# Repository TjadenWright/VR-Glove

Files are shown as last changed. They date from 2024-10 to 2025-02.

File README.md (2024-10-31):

# VR-Glove
Base Glove Front On

# 3D Printing [here](https://github.com/TjadenWright/VR-Glove/tree/main/Hardware/3D%20Print/README.md)

# Electrical [here](https://github.com/TjadenWright/VR-Glove/tree/main/Hardware/Electrical/README.md)

# Software [here](https://github.com/TjadenWright/VR-Glove/tree/main/Software/README.md)
* UWB findings [here](https://github.com/TjadenWright/VR-Glove/blob/main/Software/UWB%20VR%20Glove%20Communication/README.md)

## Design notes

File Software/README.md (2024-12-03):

# Program the VR Glove
* Open [this file](https://github.com/TjadenWright/VR-Glove/tree/main/Software/VR%20Glove%20-%20LucidVR/lucidgloves-firmware/lucidgloves-firmware.ino) in Arduino and program that to the glove arduino.
Full Glove

# Program the Receiver
## BLE
* Open [this file](https://github.com/TjadenWright/VR-Glove/blob/main/Software/Receiver%20-%20UART%20bridge/UART_bridge/UART_bridge.ino) in Arduino and program that to the receiver arduino.
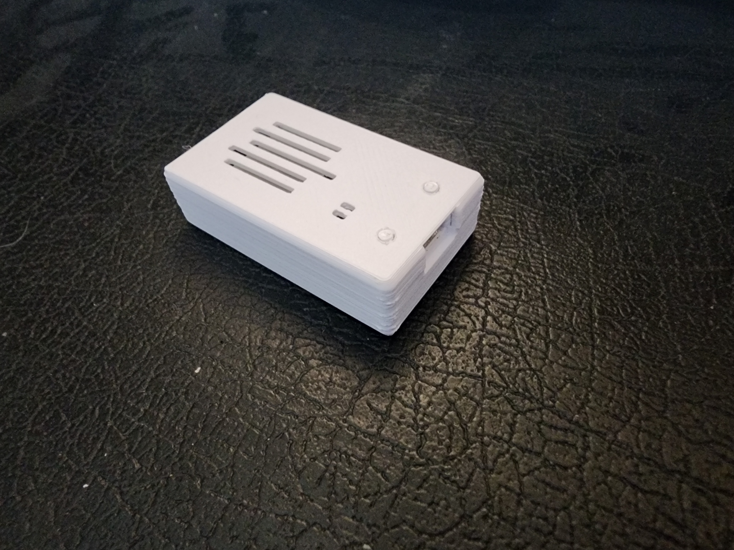
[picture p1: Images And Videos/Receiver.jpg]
Reciever


## UWB
* Open [this file](https://github.com/TjadenWright/VR-Glove/blob/main/Software/UWB%20VR%20Glove%20Communication/UWB%20Test%20Commands/BasicReceiver/BasicReceiver.ino) in Arduino and program that to the receiver arduino.

# References:
* https://github.com/DieKatzchen/lucidgloves/tree/proto5
* https://github.com/DieKatzchen/Nordic-UART-Service-Bridge

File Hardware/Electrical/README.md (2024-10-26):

# Wiring Diagram
## Glove + Joystick
* I mainly used [this](https://github.com/LucidVR/lucidgloves/wiki/Prototype-5-Wiring-Guide) wiring diagram for the glove and joystick.
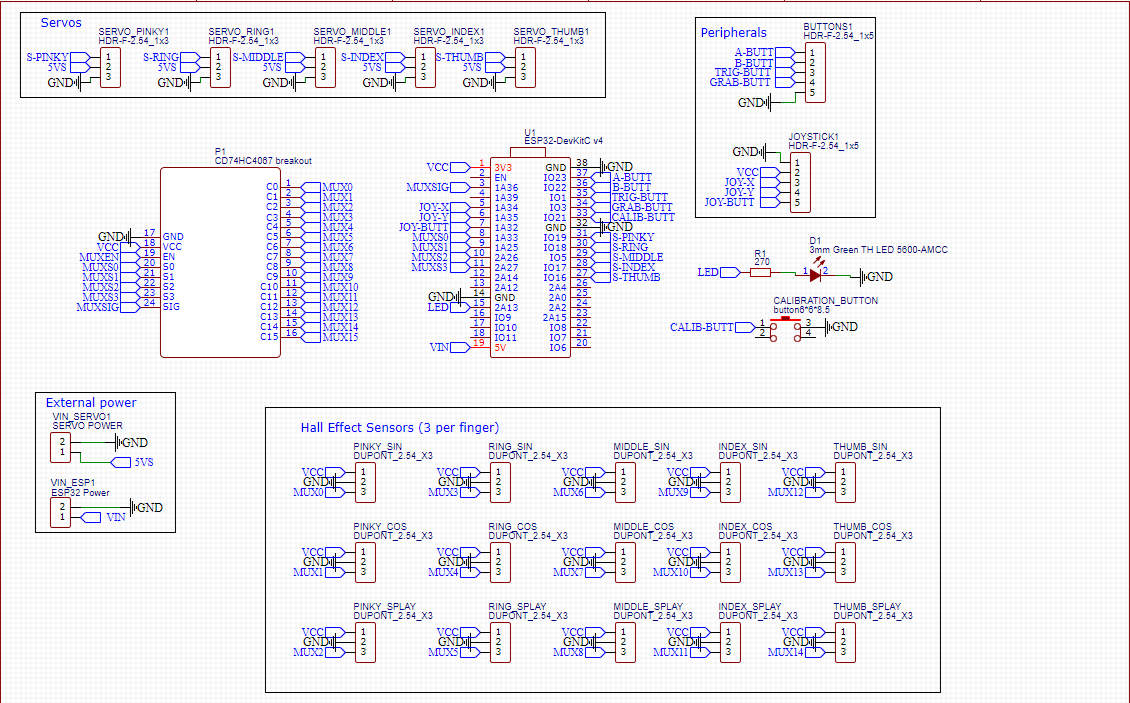
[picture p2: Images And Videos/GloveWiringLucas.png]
Glove Wiring


## Battery Pack
* For the battery circuit I used [this](https://docs.slimevr.dev/diy/tracker-schematics.html). If you want to charge while the glove is on you'll need to add two 1N5817 diodes on the output of the TP4056.
* For my specific ESP32 I needed to use a [boost converter](https://www.amazon.com/gp/product/B07L76KLRY/ref=ox_sc_act_title_3?smid=A1IU4FC9F8Y7P1&psc=1) to boost the batteries 3.7v to 5v. Do this on the wires going to the ESP32 (or the output of the TP4056).
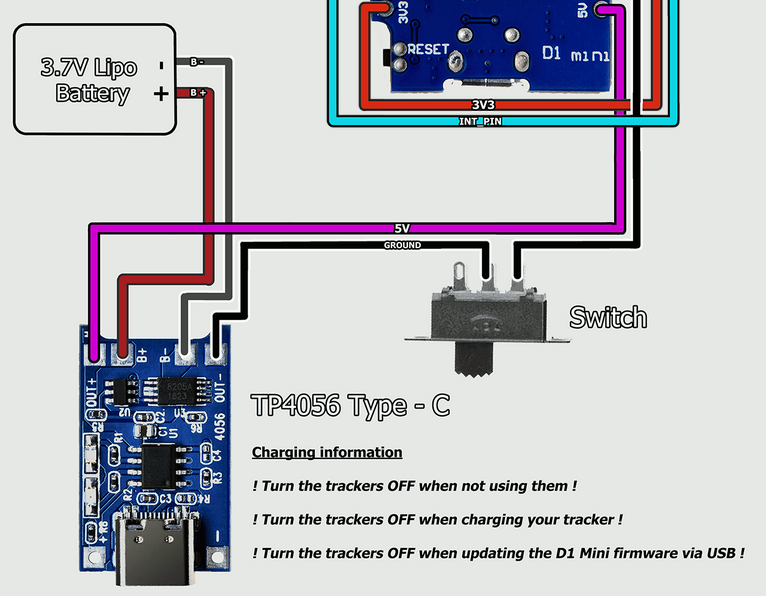
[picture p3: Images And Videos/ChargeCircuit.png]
Charge Circuit


# Parts List
## Base Glove
* 2x ESP32. I used [this](https://www.makerfabs.com/esp32-uwb-high-power-120m.html), I don't recoment that one. I just had that from another project. I recommend [this one](https://www.amazon.com/ESP-WROOM-32-Development-Microcontroller-Integrated-Compatible/dp/B0BK13HWBJ?th=1).
* 10x [Hall Effect Sensors](https://www.amazon.com/gp/aw/d/B09MSDC3GR?psc=1&ref=ppx_pop_mob_b_asin_title).
* 10x [Magnets](https://www.amazon.com/gp/aw/d/B08NZTN426?psc=1&ref=ppx_pop_mob_b_asin_title).
* 1x [Multiplexer](https://www.amazon.com/gp/aw/d/B07K7JF3HX?psc=1&ref=ppx_pop_mob_b_asin_title).
* [Wires](https://www.amazon.com/Elegoo-EL-CP-004-Multicolored-Breadboard-arduino/dp/B01EV70C78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).
* [M2 Screws](https://www.amazon.com/your-orders/pop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).
* (Optional): [Cable Sleeves](https://www.amazon.com/HERCULES-Paracord-Parachute-Black-Survival/dp/B0BD2J2DQV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).

## Joystick Upgrade
* 1x [Hall Joystick](https://www.aliexpress.us/item/3256806013522128.html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).
* 2x [Buttons](https://www.amazon.com/DAOKI-100Pcs-6x6x5mm-Momentary-Tactile/dp/B07X8T9D2Q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).
* 1x [Joystick Top](https://www.amazon.com/Joystick-Thumbsticks-Replacement-Controller-Accessories/dp/B0C3GHDLDW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).
* 4x [JST-XH Connectors](). One 3 pin (male, female) and one 4 pin (male, female) sets.
* [M2 Screws](https://www.amazon.com/your-orders/pop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).
* [Wires](https://www.amazon.com/Elegoo-EL-CP-004-Multicolored-Breadboard-arduino/dp/B01EV70C78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).
* (Optional): [Cable Sleeves](https://www.amazon.com/HERCULES-Paracord-Parachute-Black-Survival/dp/B0BD2J2DQV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).

## Battery Upgrade
* 1x [Battery](https://www.amazon.com/gp/product/B078TRCNRY/ref=ox_sc_act_title_2?smid=AQ7920MIUJ04Q&psc=1).
* 1x [Charge Board](https://www.amazon.com/HiLetgo-Lithium-Battery-Charging-Protect/dp/B00LTQU2RK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).
* 2x [JST-XH Connectors](). One 4 pin (male, female) set.
* 2x [Buttons](https://www.amazon.com/Gebildet-250VAC-Prewired-Momentary-Railway/dp/B083JWJPW5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). 
* [M2 Screws](https://www.amazon.com/your-orders/pop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).
* [Wires](https://www.amazon.com/Elegoo-EL-CP-004-Multicolored-Breadboard-arduino/dp/B01EV70C78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).
* (Optional): [Boost Converter](https://www.amazon.com/gp/product/B07L76KLRY/ref=ox_sc_act_title_3?smid=A1IU4FC9F8Y7P1&psc=1)
* (Optional): [Cable Sleeves](https://www.amazon.com/HERCULES-Paracord-Parachute-Black-Survival/dp/B0BD2J2DQV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).

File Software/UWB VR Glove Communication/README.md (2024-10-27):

# BLE 4.2 vs UWB
## BLE 4.2
* Pretty slow, at least compared to UWB. The data rate for serial is about 110 lines per second. BLE brings this data rate down to 34 lines per second or a 69.1% reduction.
BLE 4.2

## UWB
* Very fast, basically as fast as serial. The data rate for serial os about 110 lines per second. UWB brings this down to 104 lines per second or only a 5.5% reduction. 
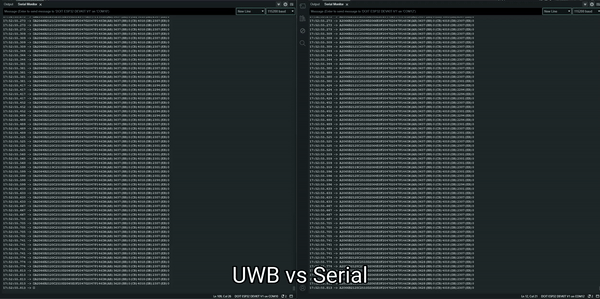
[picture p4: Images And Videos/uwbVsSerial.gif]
UWB


## UWB Board
* The board I used was the [ESP32 UWB Pro](https://www.makerfabs.com/esp32-uwb-high-power-120m.html). This also has the added benifit of having a range of ~200m, which is pretty crazy.
* If you have this board all you need to do is install [this libaray](https://github.com/TjadenWright/VR-Glove/tree/main/Software/UWB%20VR%20Glove%20Communication/README.md) and set your device to an DOIT ESP32 DEV Board.

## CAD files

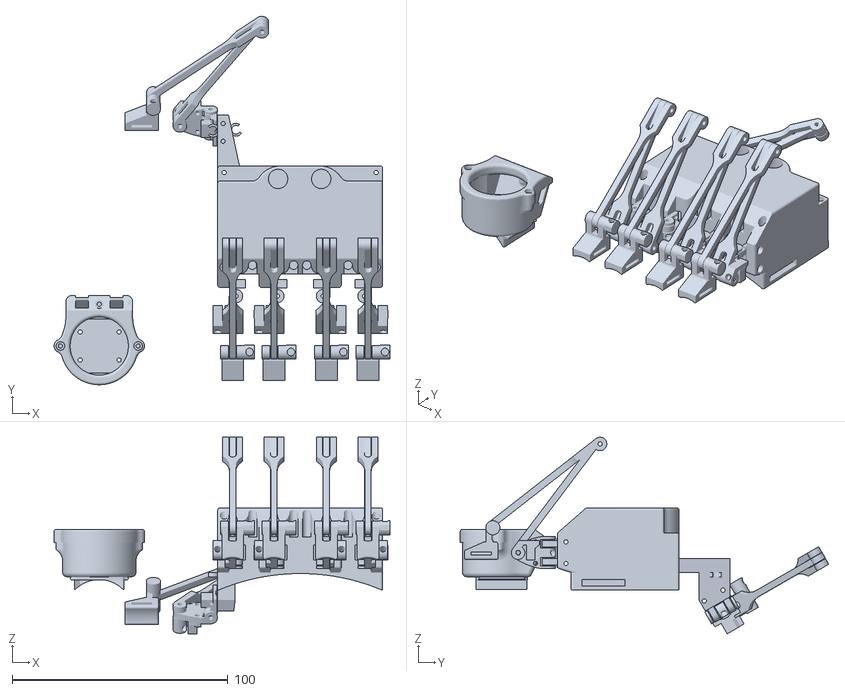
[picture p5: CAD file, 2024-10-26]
Hardware/3D Print/STLs/Full Glove/fullGlove v1.stl
155.9 x 171.0 x 91.2

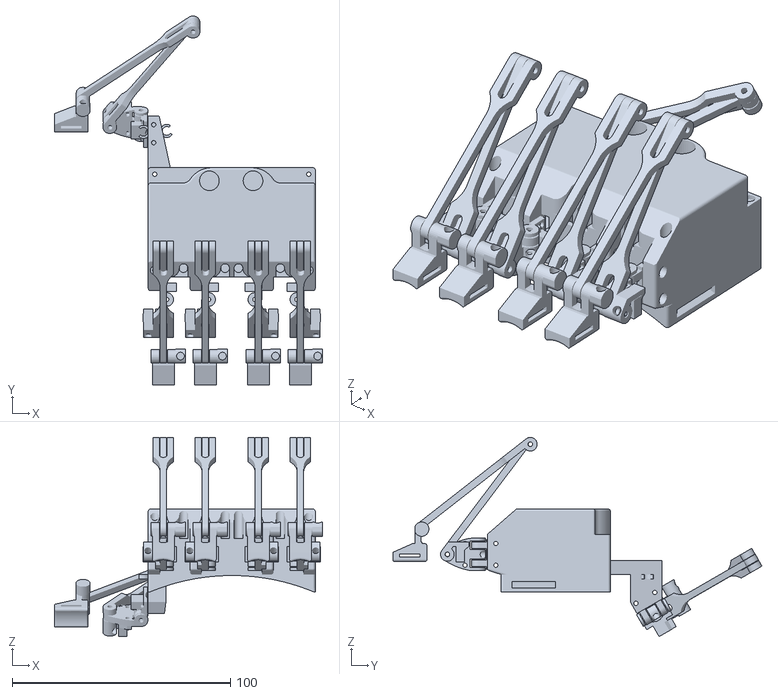
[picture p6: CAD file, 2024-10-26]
Hardware/3D Print/STLs/Base Glove + Battery Pack/baseGloveAndBatteryPack v1.stl
122.9 x 169.0 x 91.2

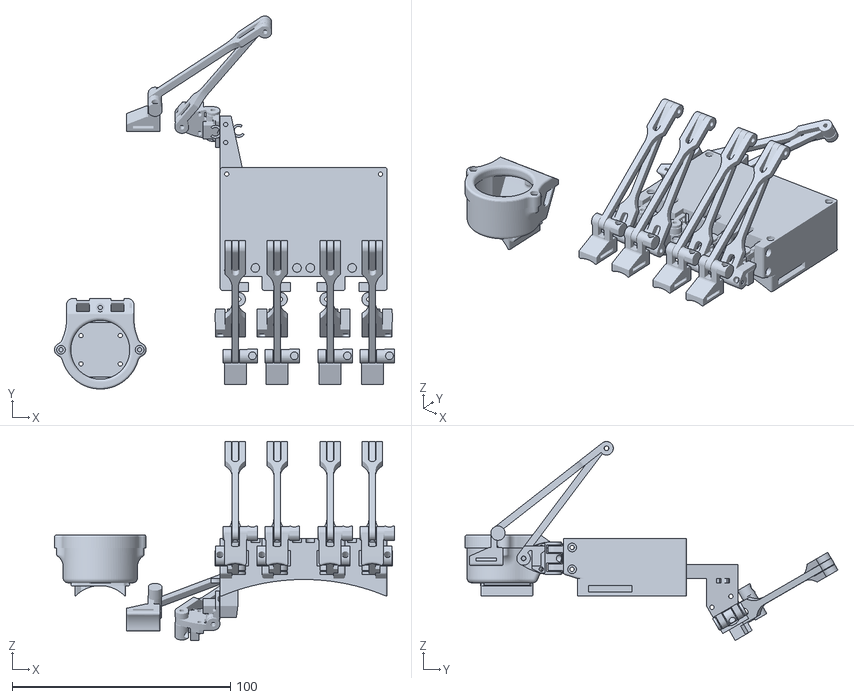
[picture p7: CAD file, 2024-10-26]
Hardware/3D Print/STLs/Base Glove + Joystick/baseGloveAndJoystick v1.stl
155.9 x 171.0 x 91.2

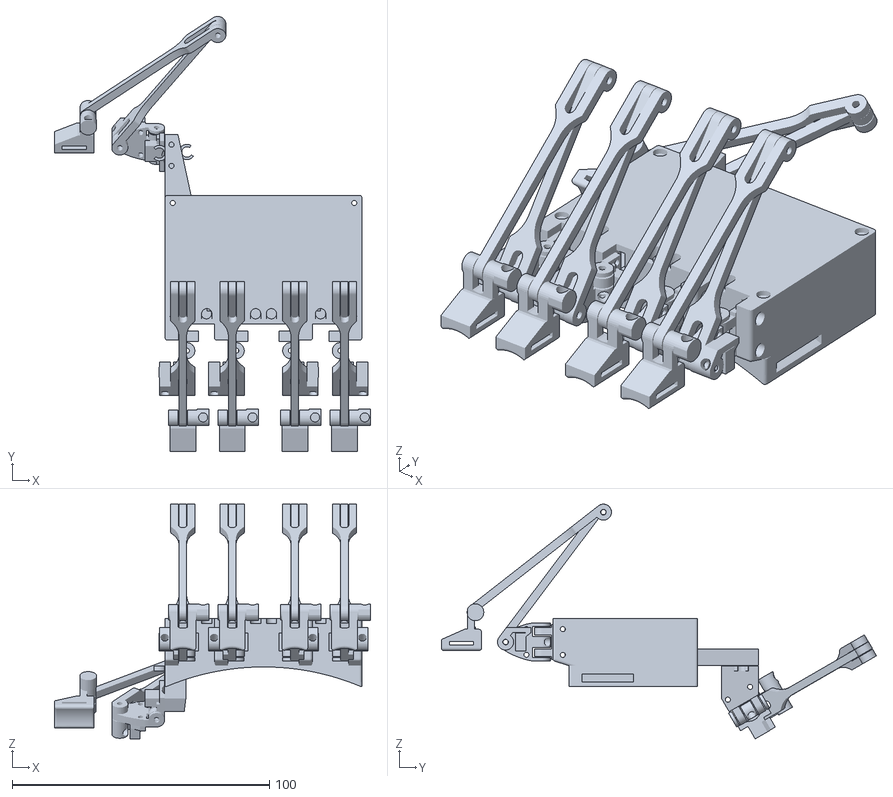
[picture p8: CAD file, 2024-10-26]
Hardware/3D Print/STLs/Base Glove/baseGlove v1.stl
122.9 x 169.0 x 91.2

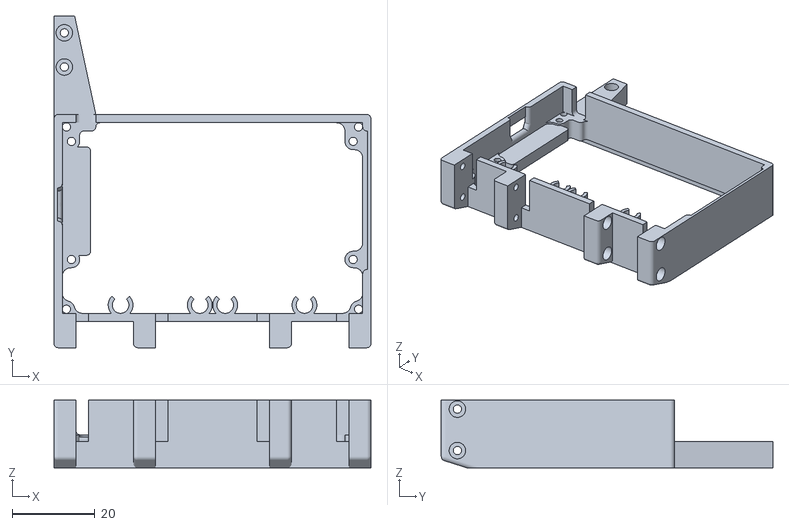
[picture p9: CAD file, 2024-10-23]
Hardware/3D Print/STLs/caseVrGlove/caseVrGlove v29.stl
76.5 x 80.0 x 16.4

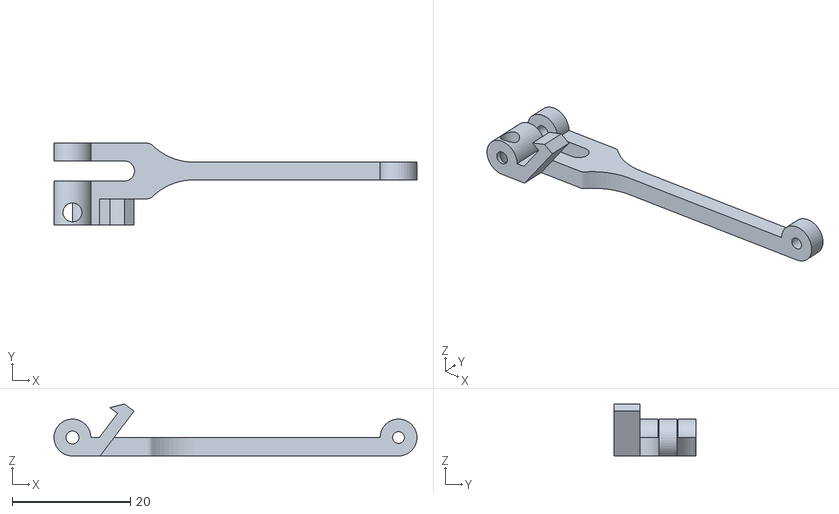
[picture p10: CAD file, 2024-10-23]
Hardware/3D Print/STLs/Parts/Base Parts/Bar Magnet/barMagnet v13small.stl
61.5 x 13.8 x 8.79

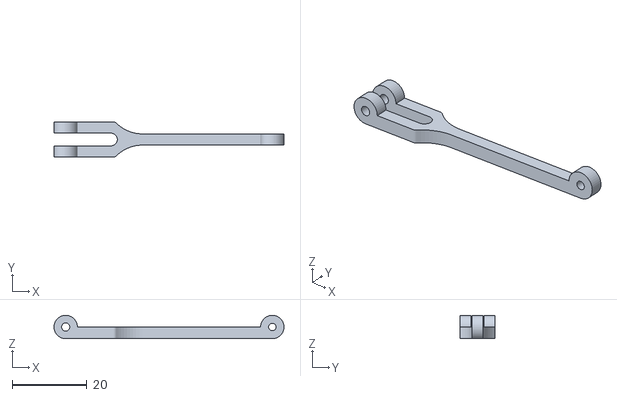
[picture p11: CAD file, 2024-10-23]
Hardware/3D Print/STLs/Parts/Base Parts/Bar/bar v8small.stl
61.5 x 9.40 x 6.25

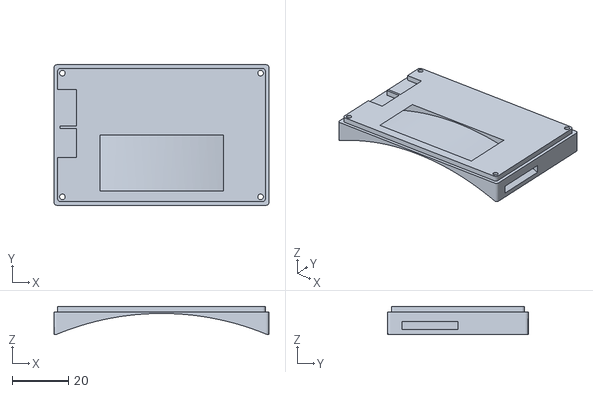
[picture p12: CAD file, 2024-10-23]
Hardware/3D Print/STLs/Parts/Base Parts/Bottom Lid Vr-Glove/bottomLidVrGlove v10.stl
76.5 x 50.0 x 10.0

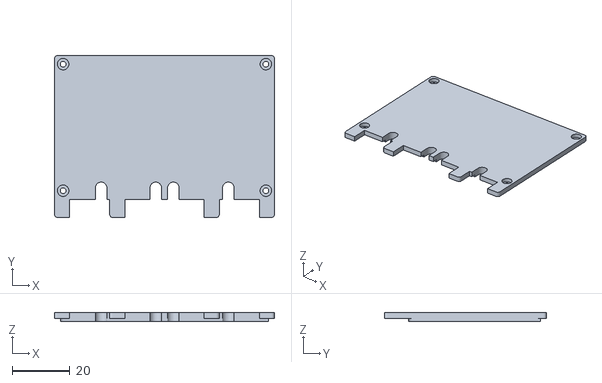
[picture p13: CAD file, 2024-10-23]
Hardware/3D Print/STLs/Parts/Base Parts/Case Lid Top/caseLidTop v7.stl
76.5 x 56.3 x 3.00

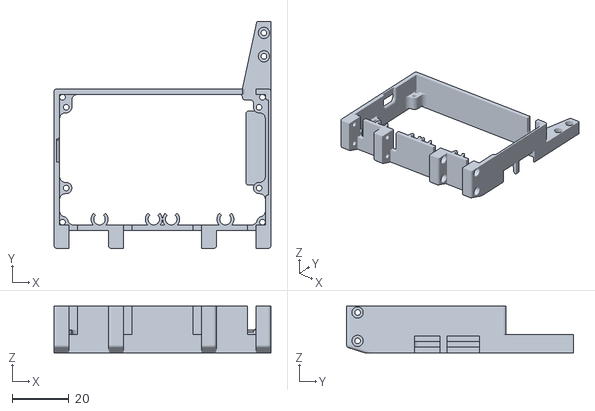
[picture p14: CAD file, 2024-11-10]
Hardware/3D Print/STLs/Parts/Base Parts/Case Vr-Glove/caseVrGloveRight v2.stl
76.5 x 80.0 x 16.4

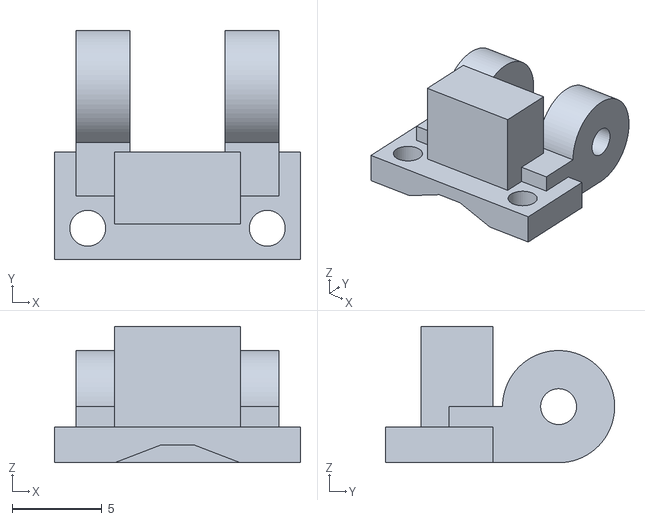
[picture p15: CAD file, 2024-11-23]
Hardware/3D Print/STLs/Parts/Base Parts/Hall Effect Holder Joint/hallEffectHolderJoint v8.stl
13.7 x 12.8 x 7.60

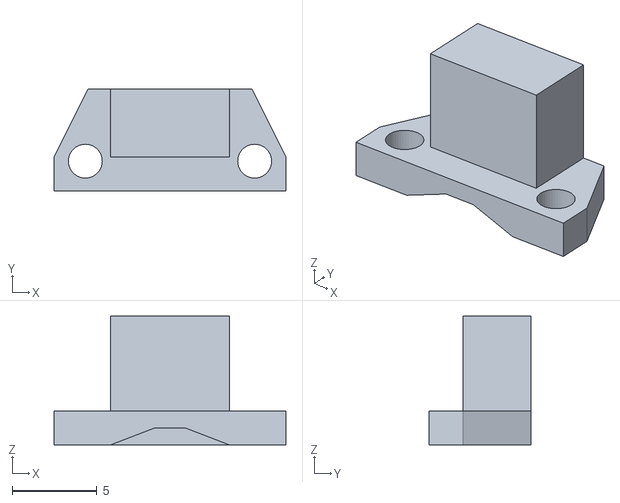
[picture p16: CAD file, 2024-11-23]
Hardware/3D Print/STLs/Parts/Base Parts/Hall Effect Holder/hallEffectHolder v9.stl
13.7 x 6.00 x 7.60

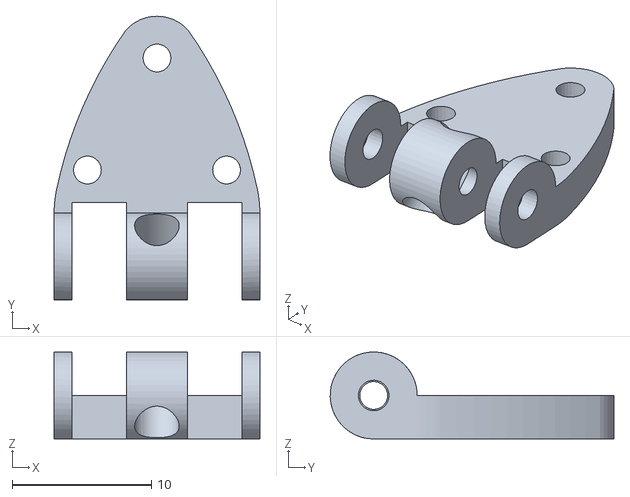
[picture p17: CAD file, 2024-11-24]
Hardware/3D Print/STLs/Parts/Base Parts/Splay Flex Joint/splayFlexJoint v21.stl
14.8 x 20.4 x 6.25

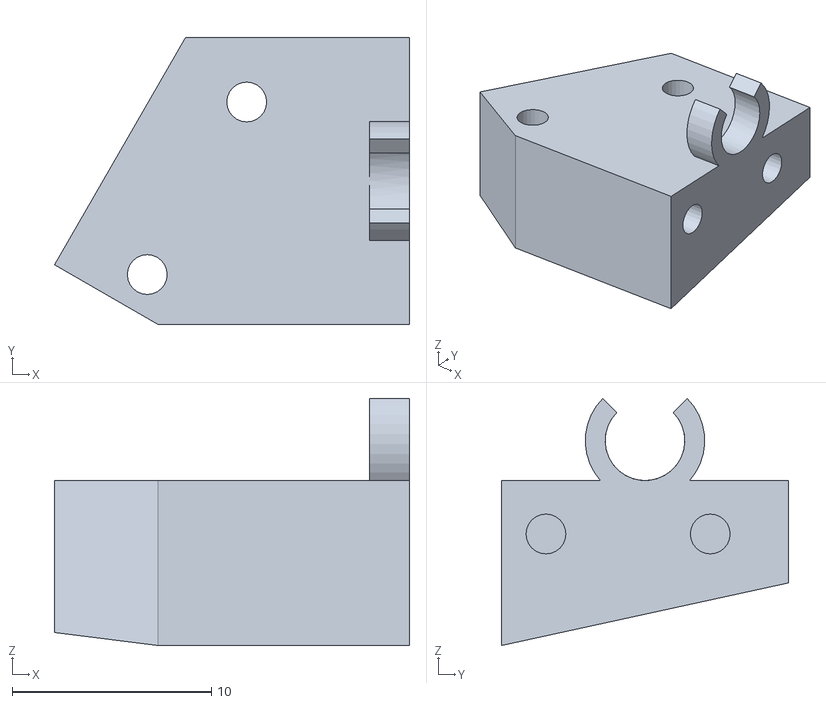
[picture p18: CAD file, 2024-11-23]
Hardware/3D Print/STLs/Parts/Base Parts/Thumb Extension/ThumbExtension v4.stl
17.8 x 14.4 x 12.4

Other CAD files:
Hardware/3D Print/STLs/Parts/Battery Pack/Battery Upgrade Lid/batteryUpgradeLid v6.stl
Hardware/3D Print/STLs/Parts/Battery Pack/Case Lid Top For Battery/caseLidTopForBattery v3.stl
Hardware/3D Print/STLs/Parts/Joystick And Buttons/Joystick Body/joystickBody v8.stl
Hardware/3D Print/STLs/Parts/Joystick And Buttons/Joystick Finger Mount/joystickFingerMount v6.stl
Hardware/3D Print/STLs/Parts/Base Parts/Bar Magnet/Old/barMagnet v10.stl
Hardware/3D Print/STLs/Parts/Base Parts/Bar Magnet/Old/barMagnet v11.stl
Hardware/3D Print/STLs/Parts/Base Parts/Bar Magnet/Old/barMagnet v4.stl
Hardware/3D Print/STLs/Parts/Base Parts/Bar Magnet/Old/barMagnet v5.stl
Hardware/3D Print/STLs/Parts/Base Parts/Bar Magnet/Old/barMagnet v6.stl
Hardware/3D Print/STLs/Parts/Base Parts/Bar Magnet/Old/barMagnet v7.stl
Hardware/3D Print/STLs/Parts/Base Parts/Bar Magnet/Old/barMagnet v9.stl
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

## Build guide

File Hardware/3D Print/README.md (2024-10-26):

# Full Glove With Battery Pack And Joystick Attachments
* The STL can be viewed [here](https://github.com/TjadenWright/VR-Glove/blob/main/Hardware/3D%20Print/STLs/Full%20Glove/fullGlove%20v1.stl).
* The 3D printing parts list can be viewed [here](https://github.com/TjadenWright/VR-Glove/blob/main/Hardware/3D%20Print/STLs/Full%20Glove/README.md).
Full Glove

# Base Glove
* The STL can be viewed [here](https://github.com/TjadenWright/VR-Glove/blob/main/Hardware/3D%20Print/STLs/Base%20Glove/baseGlove%20v1.stl).
* The 3D printing parts list can be viewed [here](https://github.com/TjadenWright/VR-Glove/blob/main/Hardware/3D%20Print/STLs/Base%20Glove/README.md).
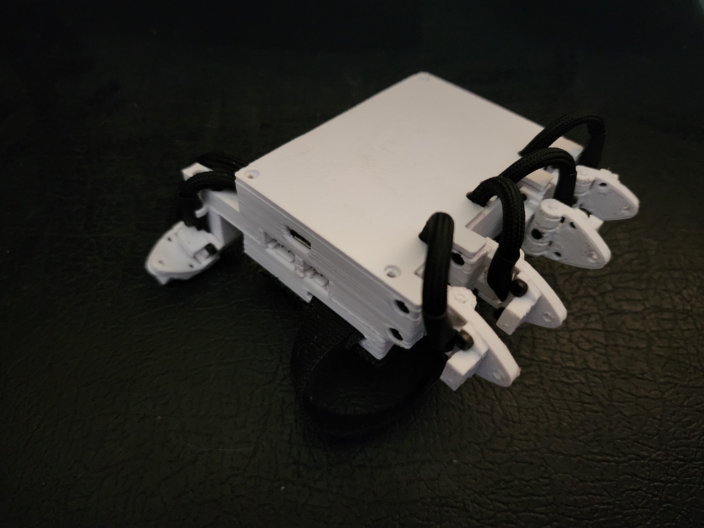
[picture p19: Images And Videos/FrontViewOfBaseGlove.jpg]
Base Glove


# Base Glove With Battery Pack
* The STL can be viewed [here](https://github.com/TjadenWright/VR-Glove/blob/main/Hardware/3D%20Print/STLs/Base%20Glove%20+%20Battery%20Pack/baseGloveAndBatteryPack%20v1.stl).
* The 3D printing parts list can be viewed [here](https://github.com/TjadenWright/VR-Glove/blob/main/Hardware/3D%20Print/STLs/Base%20Glove%20+%20Battery%20Pack/README.md).
Base Glove With Battery Pack

# Base Glove With Joystick Attachment
* The STL can be viewed [here](https://github.com/TjadenWright/VR-Glove/blob/main/Hardware/3D%20Print/STLs/Base%20Glove%20+%20Joystick/baseGloveAndJoystick%20v1.stl).
* The 3D printing parts list can be viewed [here](https://github.com/TjadenWright/VR-Glove/blob/main/Hardware/3D%20Print/STLs/Base%20Glove%20+%20Joystick/README.md).
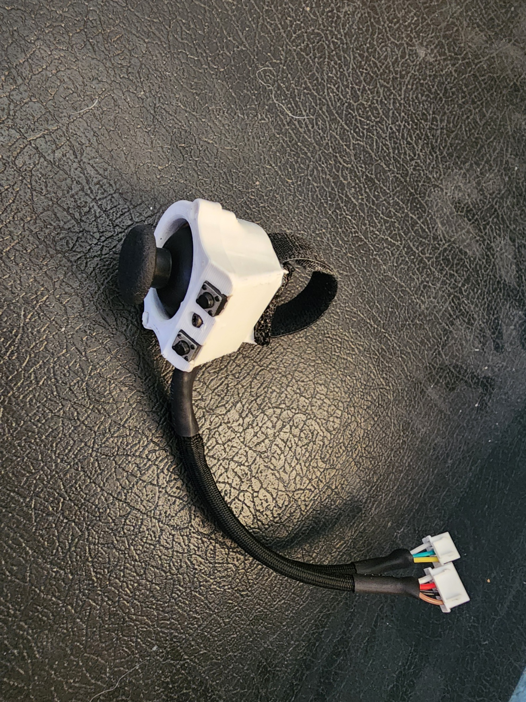
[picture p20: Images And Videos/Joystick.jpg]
Joystick


# Receiver For BLE Communication
* You can use BTSERIAL for communication (This doesn't require a receiver), but I found that to have high latency compared to BLE.
* The case I used was [this](https://www.thingiverse.com/thing:3853287).
Reciever

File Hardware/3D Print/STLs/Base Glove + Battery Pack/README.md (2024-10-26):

# Printing Parts:
* 5x [Bars](https://github.com/TjadenWright/VR-Glove/tree/main/Hardware/3D%20Print/STLs/Parts/Base%20Parts/Bar) (one being small).
* 5x [Bar Magnets](https://github.com/TjadenWright/VR-Glove/tree/main/Hardware/3D%20Print/STLs/Parts/Base%20Parts/Bar%20Magnet) (one being small).
* 1x [Bottom Lid Vr-Glove](https://github.com/TjadenWright/VR-Glove/tree/main/Hardware/3D%20Print/STLs/Parts/Base%20Parts/Bottom%20Lid%20Vr-Glove)
* 1x [Case Lid Top](https://github.com/TjadenWright/VR-Glove/tree/main/Hardware/3D%20Print/STLs/Parts/Base%20Parts/Case%20Lid%20Top)
* 1x [Case Vr-Glove](https://github.com/TjadenWright/VR-Glove/tree/main/Hardware/3D%20Print/STLs/Parts/Base%20Parts/Case%20Vr-Glove)
* 5x [Hall Effect Holders](https://github.com/TjadenWright/VR-Glove/tree/main/Hardware/3D%20Print/STLs/Parts/Base%20Parts/Hall%20Effect%20Holder)
* 5x [Hall Effect Holder Joints](https://github.com/TjadenWright/VR-Glove/tree/main/Hardware/3D%20Print/STLs/Parts/Base%20Parts/Hall%20Effect%20Holder%20Joint)
* 5x [Splay Flex Joints](https://github.com/TjadenWright/VR-Glove/tree/main/Hardware/3D%20Print/STLs/Parts/Base%20Parts/Splay%20Flex%20Joint)
* 1x [Thumb Extension](https://github.com/TjadenWright/VR-Glove/tree/main/Hardware/3D%20Print/STLs/Parts/Base%20Parts/Thumb%20Extension)

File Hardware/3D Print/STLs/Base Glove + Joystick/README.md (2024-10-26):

# Printing Parts:
* 5x [Bars](https://github.com/TjadenWright/VR-Glove/tree/main/Hardware/3D%20Print/STLs/Parts/Base%20Parts/Bar) (one being small).
* 5x [Bar Magnets](https://github.com/TjadenWright/VR-Glove/tree/main/Hardware/3D%20Print/STLs/Parts/Base%20Parts/Bar%20Magnet) (one being small).
* 1x [Bottom Lid Vr-Glove](https://github.com/TjadenWright/VR-Glove/tree/main/Hardware/3D%20Print/STLs/Parts/Base%20Parts/Bottom%20Lid%20Vr-Glove)
* 1x [Battery Upgrade Lid](https://github.com/TjadenWright/VR-Glove/tree/main/Hardware/3D%20Print/STLs/Parts/Battery%20Pack/Battery%20Upgrade%20Lid)
* 1x [Case Lid Top For Battery](https://github.com/TjadenWright/VR-Glove/tree/main/Hardware/3D%20Print/STLs/Parts/Battery%20Pack/Case%20Lid%20Top%20For%20Battery)
* 1x [Case Vr-Glove](https://github.com/TjadenWright/VR-Glove/tree/main/Hardware/3D%20Print/STLs/Parts/Base%20Parts/Case%20Vr-Glove)
* 5x [Hall Effect Holders](https://github.com/TjadenWright/VR-Glove/tree/main/Hardware/3D%20Print/STLs/Parts/Base%20Parts/Hall%20Effect%20Holder)
* 5x [Hall Effect Holder Joints](https://github.com/TjadenWright/VR-Glove/tree/main/Hardware/3D%20Print/STLs/Parts/Base%20Parts/Hall%20Effect%20Holder%20Joint)
* 5x [Splay Flex Joints](https://github.com/TjadenWright/VR-Glove/tree/main/Hardware/3D%20Print/STLs/Parts/Base%20Parts/Splay%20Flex%20Joint)
* 1x [Thumb Extension](https://github.com/TjadenWright/VR-Glove/tree/main/Hardware/3D%20Print/STLs/Parts/Base%20Parts/Thumb%20Extension)
* 1x [Joystick Body](https://github.com/TjadenWright/VR-Glove/tree/main/Hardware/3D%20Print/STLs/Parts/Joystick%20And%20Buttons/Joystick%20Body)
* 1x [Joystick Finger Mount](https://github.com/TjadenWright/VR-Glove/tree/main/Hardware/3D%20Print/STLs/Parts/Joystick%20And%20Buttons/Joystick%20Finger%20Mount)
* 1x [Joystick Lid](https://github.com/TjadenWright/VR-Glove/tree/main/Hardware/3D%20Print/STLs/Parts/Joystick%20And%20Buttons/Joystick%20Lid)
* 1x [Joystick Mount](https://github.com/TjadenWright/VR-Glove/tree/main/Hardware/3D%20Print/STLs/Parts/Joystick%20And%20Buttons/Joystick%20Mount)

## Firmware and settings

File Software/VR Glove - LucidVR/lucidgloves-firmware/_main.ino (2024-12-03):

#include <mutex>
#define ALWAYS_CALIBRATING CALIBRATION_LOOPS == -1

#define CALIB_OVERRIDE false
#if USING_CALIB_PIN && COMMUNICATION == COMM_SERIAL && PIN_CALIB == 0 && !CALIB_OVERRIDE
  #error "You can't set your calibration pin to 0 over usb. You can calibrate with the BOOT button when using bluetooth only. Set CalibOverride to true to override this."
#endif

bool calibrate = false;
bool calibButton = false;
#if USING_TWO_CALIB_PINS
bool flexionCalib = false;
bool splayCalib = false;
bool calibFlex = false;
bool calibFlexPrev = false;
bool calibSplay = false;
bool calibSplayPrev = false;
#else
bool flexionCalib = true;
bool splayCalib = true;
#endif
int* fingerPos = (int[]){0,0,0,0,0,0,0,0,0,0};

ICommunication* comm;

#if ESP32_DUAL_CORE_SET
//std::mutex fingerPosMutex;
ordered_lock* fingerPosLock = new ordered_lock();
TaskHandle_t Task1;
int threadLoops = 1;
int totalLocks = 0;
int lastMicros = 0;
int fullLoopTime = 0;
int fullLoopTotal = 0;
void getInputs(void* parameter){
    for(;;){
      fullLoopTime = micros() - lastMicros;
      fullLoopTotal += fullLoopTime;
      lastMicros = micros();
      {
        fingerPosLock->lock();
        totalLocks++;
        getFingerPositions(calibrate, calibButton, flexionCalib, splayCalib); //Save finger positions in thread

        fingerPosLock->unlock();
      }
      threadLoops++;
      if (threadLoops%100 == 0){
        vTaskDelay(1); //keep watchdog fed
      }
      delayMicroseconds(1);
    }           
}
#endif

int loops = 0;
void setup() {
  #ifndef ESP32S3
  pinMode(32, INPUT_PULLUP);
  #endif
  pinMode(DEBUG_LED, OUTPUT);
  #ifdef NEOPIXEL 
  neopixelWrite(DEBUG_LED,RGB_BRIGHTNESS,0,0); // Red 
  #else   
  digitalWrite(DEBUG_LED, HIGH); 
  #endif 

  //Serial.begin(SERIAL_BAUD_RATE);

  setupInputs();

  #if COMMUNICATION == COMM_SERIAL
    comm = new SerialCommunication();
  #elif COMMUNICATION == COMM_BTSERIAL
    comm = new BTSerialCommunication();
  #elif COMMUNICATION == COMM_BLESERIAL
    comm = new BLESerialCommunication();
  #elif COMMUNICATION == COMM_UWBSERIAL
    comm = new UWBSerialCommunication();
  #endif  
  comm->start();

  #if USING_FORCE_FEEDBACK
    setupServoHaptics();  
  #endif
  
  #if ESP32_DUAL_CORE_SET
    xTaskCreatePinnedToCore(
      getInputs, /* Function to implement the task */
      "Get_Inputs", /* Name of the task */
      10000,  /* Stack size in words */
      NULL,  /* Task input parameter */
      tskIDLE_PRIORITY,  /* Priority of the task */
      &Task1,  /* Task handle. */
      0); /* Core where the task should run */
  #endif
}


int lastMainMicros = micros();
int mainMicros = 0;
int mainMicrosTotal = 0;
int mainloops = 1;

void loop() {
  mainloops++;
  mainMicros = micros() - lastMainMicros;
  mainMicrosTotal += mainMicros;
  lastMainMicros = micros();
  
  if (comm->isOpen()){
    #if !USING_TWO_CALIB_PINS
      #if USING_CALIB_PIN
      calibButton = getButton(PIN_CALIB) != INVERT_CALIB;
      //Serial.println(getButton(PIN_CALIB));
      if (calibButton)
        loops = 0;
      #else
      calibButton = false;
      #endif

      //bool calibrate = false;
      if (loops < CALIBRATION_LOOPS || ALWAYS_CALIBRATING){
        calibrate = true;
        loops++;
      }
      else{
        calibrate = false;
      }
    #else
      // setup previous vals
      calibFlexPrev = calibFlex;
      calibSplayPrev = calibSplay;
      // get new vals
      calibFlex = getButton(PIN_CALIB_FLEX) != INVERT_CALIB_FLEX;
      calibSplay = getButton(PIN_CALIB_SPLAY) != INVERT_CALIB_SPLAY;
      
      // calibration button setup
      if(((calibFlex != calibFlexPrev) && (calibFlexPrev == 0)) || ((calibSplay != calibSplayPrev) && (calibSplayPrev == 0))){
        // if one of the buttons was just pressed set reset mode
        calibButton = true;  // reset
        calibrate = false;   // don't calibrate quite yet
      }
      else if(calibFlex || calibSplay){
        calibButton = false;  // don't reset
        calibrate = true;   // calibrate
      }
      else{
        calibButton = false;  // don't reset
        calibrate = false;   // don't calibrate
      }

      if(calibSplay){
        flexionCalib = false; // not flexion mode
        splayCalib = true;  // splay mode
      }
      else if(calibFlex){
        flexionCalib = true; // flexion mode
        splayCalib = false;  // not splay mode
      }
      else{
        flexionCalib = false; // not flexion mode
        splayCalib = false;  // not splay mode
      }
    #endif

    // Serial.print("Calib Flex: "); Serial.print(calibFlex); Serial.print(" Calib Splay: "); Serial.print(calibSplay);
    
    #if !ESP32_DUAL_CORE_SET
      getFingerPositions(calibrate, calibButton, flexionCalib, splayCalib);
    #endif
    bool joyButton = getButton(PIN_JOY_BTN) != INVERT_JOY;

    #if TRIGGER_GESTURE
    bool triggerButton = triggerGesture(fingerPos);
    #else
    bool triggerButton = getButton(PIN_TRIG_BTN) != INVERT_TRIGGER;
    #endif

    bool aButton = getButton(PIN_A_BTN) != INVERT_A;
    bool bButton = getButton(PIN_B_BTN) != INVERT_B;

    #if GRAB_GESTURE
    bool grabButton = grabGesture(fingerPos);
    #else
    bool grabButton = getButton(PIN_GRAB_BTN) != INVERT_GRAB;
    #endif

    #if PINCH_GESTURE
    bool pinchButton = pinchGesture(fingerPos);
    #else
    bool pinchButton = getButton(PIN_PNCH_BTN) != INVERT_PINCH;
    #endif

    int fingerPosCopy[10];
    int mutexTimeDone;
    
    #if MENU_BUTTON_AB
    bool menuButton = aButton && bButton; // set menu to a + b
    if(menuButton){
      aButton = bButton = false;  // set a and b to false if menu is true.
    }
    #else
    bool menuButton =  getButton(PIN_MENU_BTN) != INVERT_MENU;
    #endif

    {
      #if ESP32_DUAL_CORE_SET
      int mutexTime = micros();
      //const std::lock_guard<std::mutex> lock(fingerPosMutex);
      fingerPosLock->lock();
      mutexTimeDone = micros()-mutexTime;
      #endif
      //memcpy(fingerPosCopy, fingerPos, sizeof(fingerPos));
      for (int i = 0; i < 10; i++){
        fingerPosCopy[i] = fingerPos[i];
      }
      #if ESP32_DUAL_CORE_SET
      fingerPosLock->unlock();
      #endif
      
    }
    comm->output(encode(fingerPosCopy, getJoyX(), getJoyY(), joyButton, triggerButton, aButton, bButton, grabButton, pinchButton, calibButton, menuButton));
    #if USING_FORCE_FEEDBACK
      char received[100];
      if (comm->readData(received)){
        int hapticLimits[5];
        //This check is a temporary hack to fix an issue with haptics on v0.5 of the driver, will make it more snobby code later
        if(String(received).length() >= 5) {
           decodeData(received, hapticLimits);
           writeServoHaptics(hapticLimits); 
        }
      }
    #endif
    delay(LOOP_TIME);
  }
}

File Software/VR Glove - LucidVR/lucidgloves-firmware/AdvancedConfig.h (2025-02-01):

//Advanced settings, only for the pros XD

#define LOOP_TIME 1 //How much time between data sends (ms), set to 0 for a good time :)
#define CALIBRATION_LOOPS -1//How many loops should be calibrated. Set to -1 to always be calibrated.

//Encoding
#define ENCODING ENCODE_ALPHA

#define NUM_FINGERS 5

//Bluetooth advaned settings
#define BT_ECHO false //Should the bluetooth data be echoed over serial for debugging

//ESP32 Specific Settings
#define ESP32_DUAL_CORE false //Should inputs be handled on a separate core for communication for more accurate rotation counting

//Finger indeces (not used for legacy)
#define PINKY_IND 4
#define RING_IND 3
#define MIDDLE_IND 2
#define INDEX_IND 1
#define THUMB_IND 0

//Automatically set ANALOG_MAX depending on the microcontroller
#if defined(__AVR__)
#define ANALOG_MAX 1023
#elif defined(ESP32)
#define ANALOG_MAX 4095 
#endif


#define MULTIPLEXER_DELAY   5 //How many microseconds should be delayed between multiplexer reads

//ANALOG_MAX OVERRIDE:
//#define ANALOG_MAX 4095 //uncomment and set as needed

#ifndef ANALOG_MAX
#error "This board doesn't have an auto ANALOG_MAX assignment, please set it manually by uncommenting the line below ANALOG_MAX OVERRIDE in AdvancedConfig.h"
#endif

#define JOYSTICK_MAPPING true // allows joystick to go from 0-3.3v if it can't
#define JOYSTICK_X_MAX 3070
#define JOYSTICK_X_MIN 760
#define JOYSTICK_Y_MAX 2650
#define JOYSTICK_Y_MIN 460

//Filtering and clamping analog inputs
#define CLAMP_ANALOG_MAP true //clamp the mapped analog values from 0 to ANALOG_MAX

// Enable and set min and max to match your sensor's expected raw value range
// This discards any spurious values outside of the useful range
#define CLAMP_SENSORS false  //clamp the raw sensor values
#define CLAMP_SENSORS_DISCARD false // clanp the raw sensor values by discarding bad ones.
#define CLAMP_MIN 1000  //the minimum value from the flexion sensors
#define CLAMP_MAX 2500  //the maximum value from the flexion sensors

// You must install RunningMedian library to use this feature
// https://www.arduino.cc/reference/en/libraries/runningmedian/
#define ENABLE_MEDIAN_FILTER true //use the median of the previous values, helps reduce noise
#define MEDIAN_SAMPLES 30

//intermediate filtering. Options are INTERFILTER_NONE, INTERFILTER_LIMITS (filter is only used for limit calib), INTERFILTER_ALL (filter all the way)
#define INTERFILTER_MODE INTERFILTER_LIMITS
#define INTERFILTER_SAMPLES 100

//ESP dual core hardware check
#if defined(ESP32) && ESP32_DUAL_CORE
  #define ESP32_DUAL_CORE_SET true
#endif

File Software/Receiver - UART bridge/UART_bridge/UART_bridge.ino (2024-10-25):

/** Nordic UART Service Bridge:
 *
 *  Connects with a BLE device specified by name and bridges the Nordic UART Service to its serial port
 *
 *  Created: on April 2 2024
 *      Author: DieKatzchen
 *
*/

#include <NimBLEDevice.h>

#define GLOVENAME "lucidgloves-left"
#define LED 2
//#define _DEBUG //Uncomment to turn on debug messages

void scanEndedCB(NimBLEScanResults results);

static NimBLEAdvertisedDevice* advDevice;
static NimBLERemoteService* pSvc;
static NimBLERemoteCharacteristic* rxChr;
static NimBLERemoteCharacteristic* txChr;

static bool doConnect = false;
static bool connected = false;
static uint32_t scanTime = 0; /** 0 = scan forever */

static NimBLEScan* pScan;

class ClientCallbacks : public NimBLEClientCallbacks {
    void onDisconnect(NimBLEClient* pClient) {
        #ifdef _DEBUG
        Serial.print(pClient->getPeerAddress().toString().c_str());
        Serial.println(" Disconnected - Starting scan");
        #endif
        digitalWrite(LED, LOW);
        connected = false;

        NimBLEDevice::deleteClient(pClient);
        NimBLEDevice::getScan()->start(scanTime, scanEndedCB);
    };
};

/** Define a class to handle the callbacks when advertisments are received */
class AdvertisedDeviceCallbacks: public NimBLEAdvertisedDeviceCallbacks {

    void onResult(NimBLEAdvertisedDevice* advertisedDevice) {
        #ifdef _DEBUG
        Serial.print("Advertised Device found: ");
        Serial.println(advertisedDevice->toString().c_str());
        #endif
        std::string deviceName = advertisedDevice->getName();
        if(deviceName == GLOVENAME)
        {
            #ifdef _DEBUG
            Serial.println("Found Glove");
            #endif
            /** stop scan before connecting */
            NimBLEDevice::getScan()->stop();
            /** Save the device reference in a global for the client to use*/
            advDevice = advertisedDevice;
            /** Ready to connect now */
            doConnect = true;
        }
    };
};


/** Notification / Indication receiving handler callback */
void notifyCB(NimBLERemoteCharacteristic* pRemoteCharacteristic, uint8_t* pData, size_t length, bool isNotify){
    Serial.print((char*)pData);
}

/** Callback to process the results of the last scan or restart it */
void scanEndedCB(NimBLEScanResults results){
    #ifdef _DEBUG
    Serial.println("Scan Ended");
    #endif
}

/** Create a single global instance of the callback class to be used by all clients */
static ClientCallbacks clientCB;

/** Handles the provisioning of clients and connects / interfaces with the server */
bool connectToServer() {
    NimBLEClient* pClient = nullptr;
    /** Check if we have a client we should reuse first **/
    if(NimBLEDevice::getClientListSize()) {
        // Special case when we already know this device, we send false as the
        //  second argument in connect() to prevent refreshing the service database.
        //  This saves considerable time and power.
        //
        pClient = NimBLEDevice::getClientByPeerAddress(advDevice->getAddress());
        if(pClient){
            if(!pClient->connect(advDevice, false)) {
                #ifdef _DEBUG
                Serial.println("Reconnect failed");
                #endif
                return false;
            }
            #ifdef _DEBUG
            Serial.println("Reconnected client");
            #endif
            //connected = true;
        }
        // We don't already have a client that knows this device,
        //  we will check for a client that is disconnected that we can use.
        //
        else {
            pClient = NimBLEDevice::getDisconnectedClient();
        }
    }

    /** No client to reuse? Create a new one. */
    if(!pClient) {
        if(NimBLEDevice::getClientListSize() >= NIMBLE_MAX_CONNECTIONS) {
            #ifdef _DEBUG
            Serial.println("Max clients reached - no more connections available");
            #endif
            return false;
        }

        pClient = NimBLEDevice::createClient();
        #ifdef _DEBUG
        Serial.println("New client created");
        #endif
        pClient->setClientCallbacks(&clientCB, false);
        /** Set initial connection parameters: These settings are 15ms interval, 0 latency, 120ms timout.
         *  These settings are safe for 3 clients to connect reliably, can go faster if you have less
         *  connections. Timeout should be a multiple of the interval, minimum is 100ms.
         *  Min interval: 12 * 1.25ms = 15, Max interval: 12 * 1.25ms = 15, 0 latency, 51 * 10ms = 510ms timeout
         */
        pClient->setConnectionParams(12,12,0,51);
        /** Set how long we are willing to wait for the connection to complete (seconds), default is 30. */
        pClient->setConnectTimeout(5);


        if (!pClient->connect(advDevice)) {
            /** Created a client but failed to connect, don't need to keep it as it has no data */
            NimBLEDevice::deleteClient(pClient);
            #ifdef _DEBUG
            Serial.println("Failed to connect, deleted client");
            #endif
            return false;
        }
    }

    if(!pClient->isConnected()) {
        if (!pClient->connect(advDevice)) {
            #ifdef _DEBUG
            Serial.println("Failed to connect");
            #endif
            return false;
        }
    }

    #ifdef _DEBUG
    Serial.print("Connected to: ");
    Serial.println(pClient->getPeerAddress().toString().c_str());
    Serial.print("RSSI: ");
    Serial.println(pClient->getRssi());
    #endif

    /** Now we can read/write/subscribe the charateristics of the services we are interested in */
    pSvc = pClient->getService("6E400001-B5A3-F393-E0A9-E50E24DCCA9E");
    if(pSvc) {     /** make sure it's not null */
        txChr = pSvc->getCharacteristic("6E400003-B5A3-F393-E0A9-E50E24DCCA9E");
        if(!txChr){
          #ifdef _DEBUG
          Serial.println("Nordic TX characteristic not found.");
          #endif
          return false;
        }
        /*if(txChr) {     // make sure it's not null
            if(txChr->canNotify()) {
                if(!txChr->subscribe(true, notifyCB)) {
                    // Disconnect if subscribe failed
                    pClient->disconnect();
                    return false;
                }
            }
        }*/
        rxChr = pSvc->getCharacteristic("6E400002-B5A3-F393-E0A9-E50E24DCCA9E");
        if(!rxChr){
          #ifdef _DEBUG
          Serial.println("Nordic RX characteristic not found.");
          #endif
          return false;
        }
    } else {
        #ifdef _DEBUG
        Serial.println("Nordic UART service not found.");
        #endif
        return false;
    }

    //Serial.println("Done with this device!");
    doConnect = false;
    return true;
}
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

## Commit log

2024-10-23 added main case
    [caseVrGlove v11.stl, caseVrGlove v15.stl, caseVrGlove v17.stl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]
2024-10-23 fixed names
    [caseVrGlove v06.stl, caseVrGlove v09.stl]
2024-10-23 added all fusion base model files
    [bar2.f3d, bar2Magnet.f3d, bottomLidVrGlove v10.stl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]
2024-10-23 added all fusion files and base stls
    [ThumbExtension v1.stl, ThumbExtension v2.stl, bar v1.stl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]
2024-10-23 all stls and fusion files uploaded
    [batteryUpgradeLid v1.stl, batteryUpgradeLid v6.stl, caseLidTopForBattery v2.stl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]
2024-10-25 first demo glove code that manually sets finger max and mins
2024-10-26 updated to use calibrate buttons for flexion and splay
2024-10-26 added sampling just for configuration of the fingers. Set it to not median filter when in use.
2024-10-26 try to show stl on a readme?
2024-10-26 try full glove stl
    [fullGlove v1.stl]
2024-10-26 test massive stl
2024-10-26 added some different options for building
    [ThumbExtension v1.stl, ThumbExtension v2.stl, bar v1.stl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]
2024-10-26 added printing parts for base model
2024-10-26 3d print readmes
2024-10-26 fixed uart bridge link
2024-10-26 finished 3d print and software readme
2024-10-26 added charging stuff
2024-10-26 fixed bars
    [bar v6.stl, bar v8.stl]
2024-10-26 Update and rename input.ino to input.ino changed inter filter samples
2024-10-26 update from phone did not work well...
    [input.ino]
2024-10-27 something is bugged in lucids firmware with dual cores.
    [AdvancedConfig.h]
2024-10-27 Testing out uwb. Might actually be a viable option. Serial does 55 messages per 1/2 second. UWB - 52, and BLE (4.2) - 17. This just requires you to get a 50+ dollar board... Probably better to do BLE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
2024-11-02 Updated code to switch between uwb channels. It looks like channels 4 and 7 are the best on the dw1000. Added sampling for joystick. Fixed auto calibration not reseting max and mins. Fixed trigger no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
    [AdvancedConfig.h, BasicReceiver.ino, BasicSender.ino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]
2024-11-10 starting to make right glove
    [caseVrGloveRight v2.stl]
2024-11-23 Updated hall effect holders and thumb extension
    [ThumbExtension v2.stl, ThumbExtension v4.stl, hallEffectHolder v8.stl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]
2024-11-24 Updated splay joint
    [splayFlexJoint v15.stl, splayFlexJoint v21.stl, splayFlexJoint.f3z]
2025-02-01 Updated config to have clamp analog sensors. Updated right side glove with correctjoystick and splay orientation.
    [AdvancedConfig.h, lucidgloves-firmware.ino]
